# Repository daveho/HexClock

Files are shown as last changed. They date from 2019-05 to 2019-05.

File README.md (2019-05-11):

# HexClock

This is a somewhat silly project to make a digital clock that displays the current time (hour and minute) in hexadecimal.

Here is a picture of the prototype (click to embiggen):

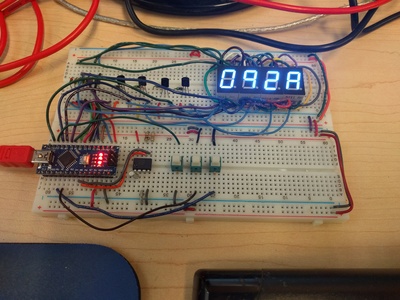
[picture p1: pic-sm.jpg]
HexClock prototype


The [KiCad](http://kicad-pcb.org/) schematic for the prototype circuit is in the [hw\_proto](hw_proto) directory.  The required parts are:

* Arduino Nano
* DS1307 i2c real time clock chip
* 4 common anode 7 segment displays
* 4 2N3906 PNP transistors (to switch common anode voltages for LED displays)
* 4 4.7k Ohm resistors (to drive gates of the PNP transistors)
* 2 1K pull-up resistors for i2c SDA and SCL lines
* 7 current limiting resistors for segment cathodes (I used 220 Ohm)
* 3 normally open pushbutton switches
* 5V power supply of some kind

The software is in the [HexClock](HexClock) directory.  It requires the [RTCLib](https://github.com/adafruit/RTClib) and [Bounce2](https://github.com/thomasfredericks/Bounce2) libraries, both of which you can install using the Arduino package manager.

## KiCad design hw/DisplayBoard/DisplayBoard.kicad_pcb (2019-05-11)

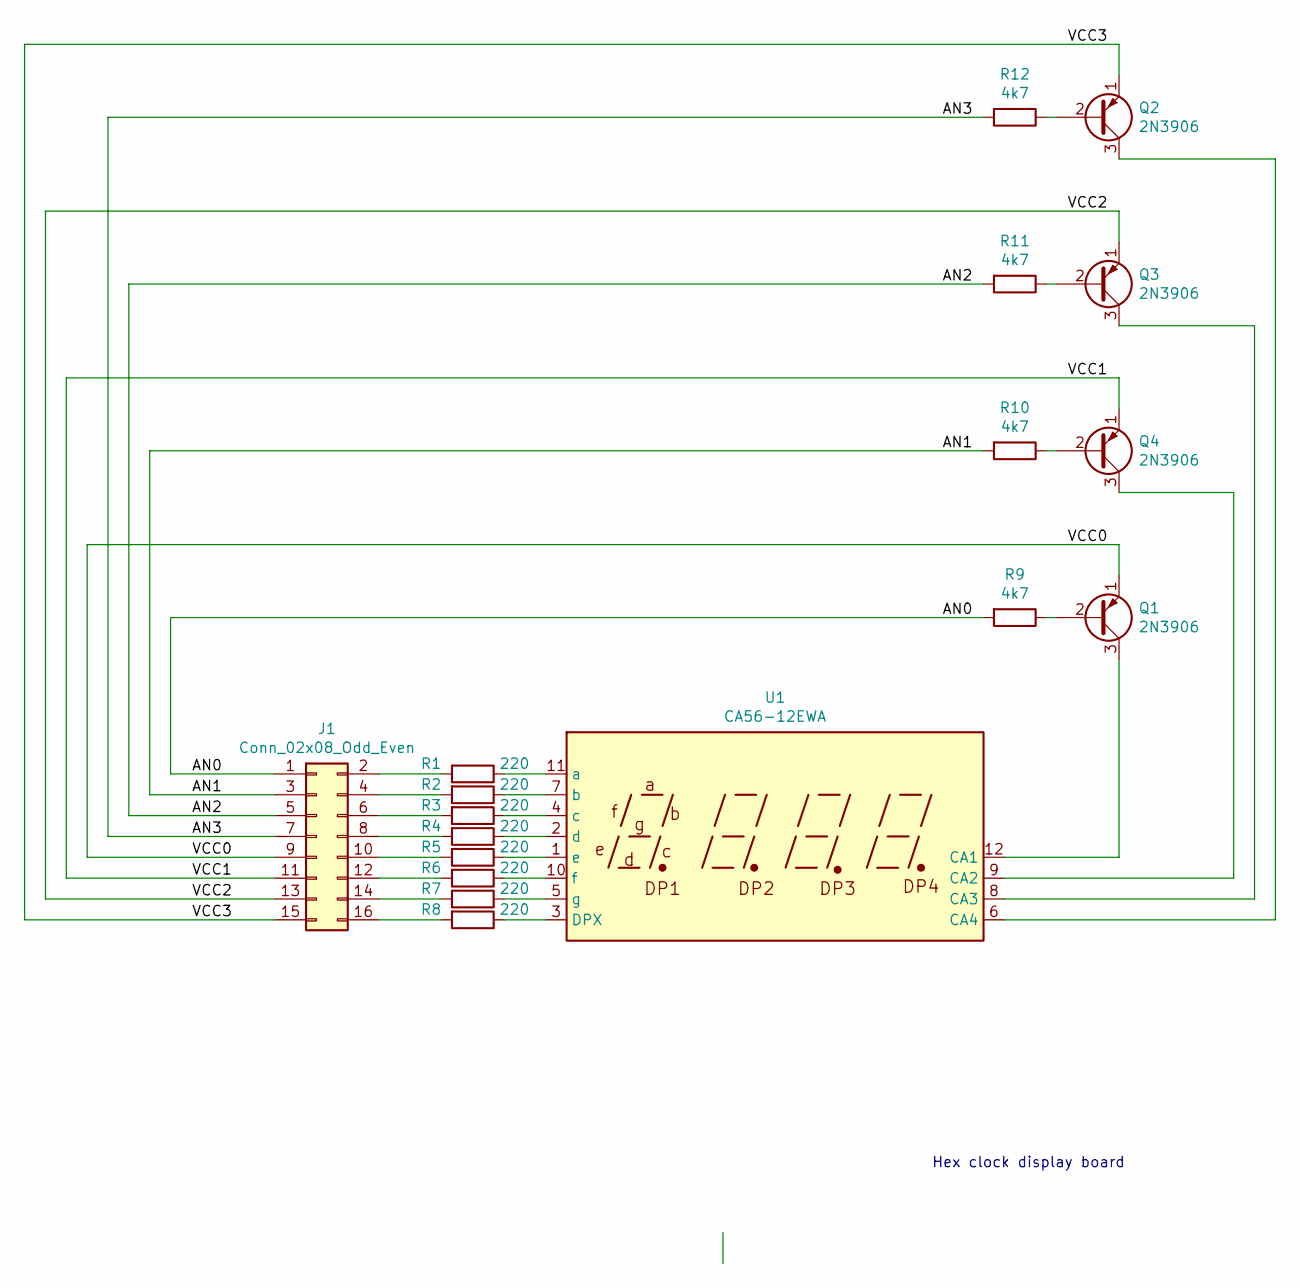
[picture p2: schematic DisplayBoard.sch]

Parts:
J1: Conn_02x08_Odd_Even; Pin_Header_Straight_2x08_Pitch2.54mm
Q1, Q2, Q3, Q4: 2N3906; TO-92_Inline_Narrow_Oval
R1, R2, R3, R4, R5, R6, R7, R8: 220; R_Axial_DIN0207_L6.3mm_D2.5mm_P7.62mm_Horizontal
R9, R10, R11, R12: 4k7; R_Axial_DIN0207_L6.3mm_D2.5mm_P7.62mm_Horizontal
U1: CA56-12EWA

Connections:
/AN0: J1.1, R9.2
/AN1: J1.3, R10.2
/AN2: J1.5, R11.2
/AN3: J1.7, R12.2
/VCC0: J1.9, Q1.1 (E)
/VCC1: J1.11, Q4.1 (E)
/VCC2: J1.13, Q3.1 (E)
/VCC3: J1.15, Q2.1 (E)
unnamed: J1.2, R1.2
unnamed: J1.4, R2.2
unnamed: J1.6, R3.2
unnamed: J1.8, R4.2
unnamed: J1.10, R5.2
unnamed: J1.12, R6.2
unnamed: J1.14, R7.2
unnamed: J1.16, R8.2
unnamed: Q1.2 (B), R9.1
unnamed: Q1.3 (C), U1.12 (CA1)
unnamed: Q2.2 (B), R12.1
unnamed: Q2.3 (C), U1.6 (CA4)
unnamed: Q3.2 (B), R11.1
unnamed: Q3.3 (C), U1.8 (CA3)
unnamed: Q4.2 (B), R10.1
unnamed: Q4.3 (C), U1.9 (CA2)
unnamed: R1.1, U1.11 (a)
unnamed: R2.1, U1.7 (b)
unnamed: R3.1, U1.4 (c)
unnamed: R4.1, U1.2 (d)
unnamed: R5.1, U1.1 (e)
unnamed: R6.1, U1.10 (f)
unnamed: R7.1, U1.5 (g)
unnamed: R8.1, U1.3 (DPX)

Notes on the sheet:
Hex clock display board

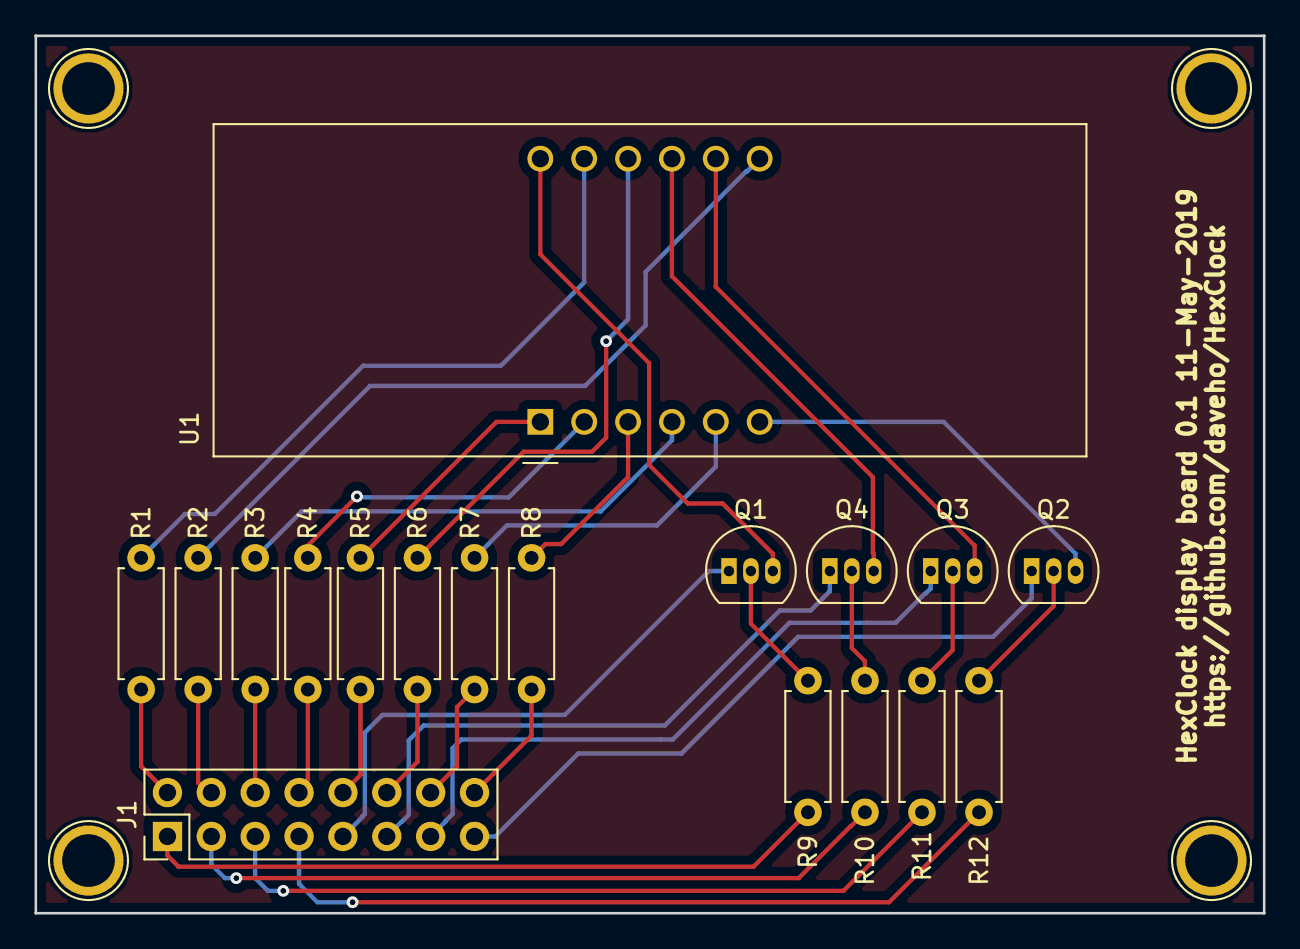
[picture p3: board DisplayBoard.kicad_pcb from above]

Board: 2 copper layers, 71.1 x 50.8 mm, 18 parts (0 on the bottom side), 32 nets.

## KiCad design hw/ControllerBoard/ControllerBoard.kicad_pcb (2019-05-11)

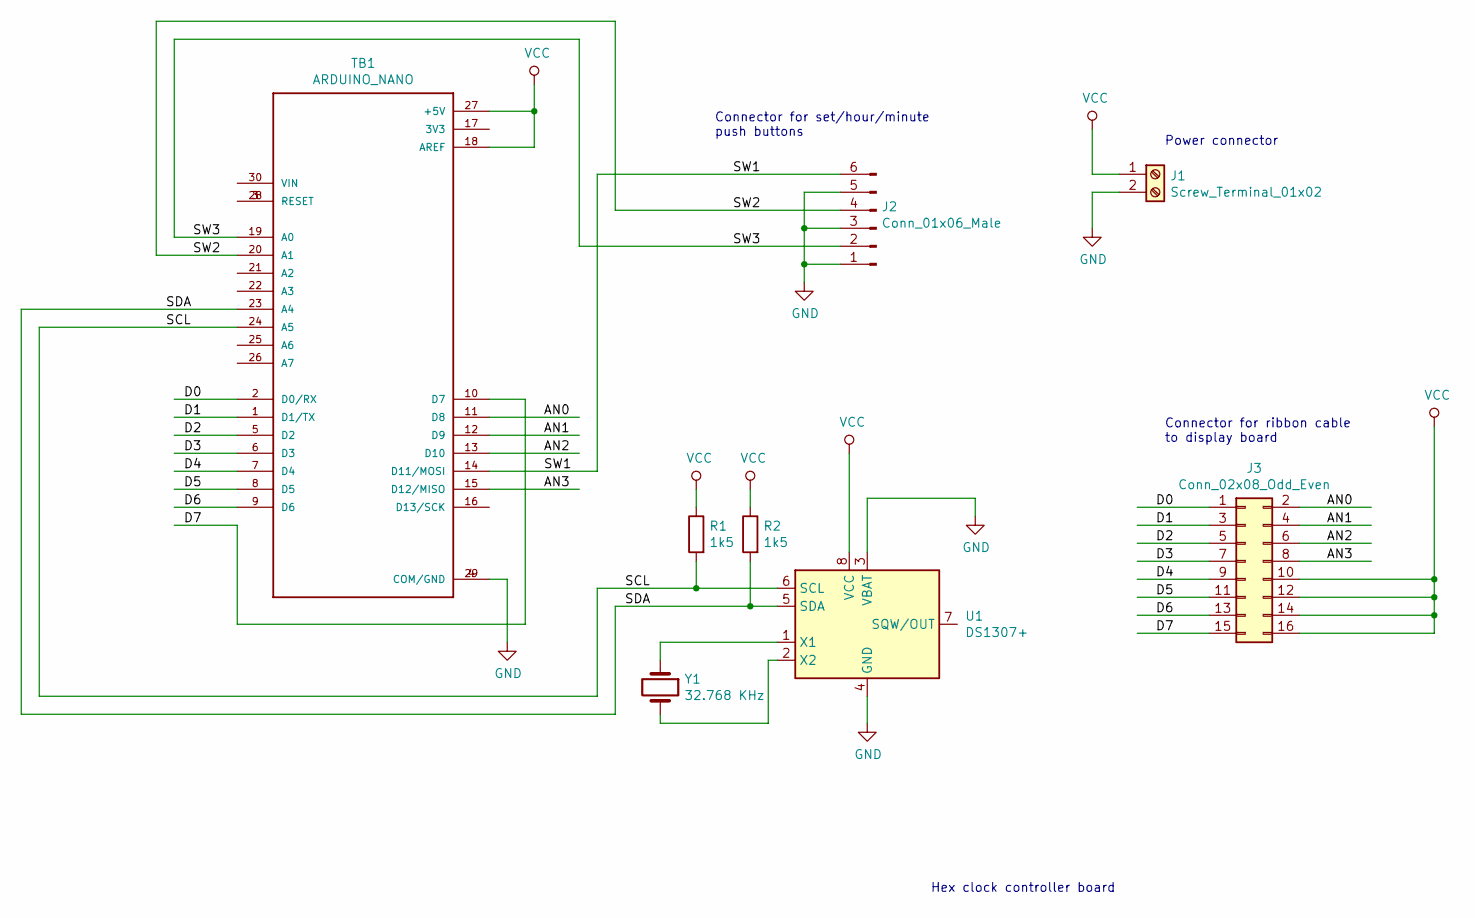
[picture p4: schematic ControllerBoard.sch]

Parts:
J1: Screw_Terminal_01x02; TerminalBlock_Phoenix_MKDS-1,5-2_1x02_P5.00mm_Horizontal
J2: Conn_01x06_Male; Pin_Header_Straight_1x06_Pitch2.54mm
J3: Conn_02x08_Odd_Even; Pin_Header_Straight_2x08_Pitch2.54mm
R1, R2: 1k5; R_Axial_DIN0207_L6.3mm_D2.5mm_P7.62mm_Horizontal
TB1: ARDUINO_NANO; SHIELD_ARDUINO_NANO
U1: DS1307+; DIP-8_W7.62mm_Socket
Y1: 32.768 KHz; Crystal_C38-LF_d3.0mm_l8.0mm_Horizontal

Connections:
/AN0: J3.2, TB1.11 (D8)
/AN1: J3.4, TB1.12 (D9)
/AN2: J3.6, TB1.13 (D10)
/AN3: J3.8, TB1.15 (D12/MISO)
/D0: J3.1, TB1.2 (D0/RX)
/D1: J3.3, TB1.1 (D1/TX)
/D2: J3.5, TB1.5 (D2)
/D3: J3.7, TB1.6 (D3)
/D4: J3.9, TB1.7 (D4)
/D5: J3.11, TB1.8 (D5)
/D6: J3.13, TB1.9 (D6)
/D7: J3.15, TB1.10 (D7)
/SCL: R1.2, TB1.24 (A5), U1.6 (SCL)
/SDA: R2.2, TB1.23 (A4), U1.5 (SDA)
/SW1: J2.6, TB1.14 (D11/MOSI)
/SW2: J2.4, TB1.20 (A1)
/SW3: J2.2, TB1.19 (A0)
GND: J1.2, J2.1, J2.3, J2.5, TB1.4 (COM/GND), TB1.29 (COM/GND), U1.3 (VBAT), U1.4 (GND)
unnamed: TB1.3 (RESET), TB1.28 (RESET)
unnamed: U1.1 (X1), Y1.1
unnamed: U1.2 (X2), Y1.2
VCC: J1.1, J3.10, J3.12, J3.14, J3.16, R1.1, R2.1, TB1.18 (AREF), TB1.27 (+5V), U1.8 (VCC)

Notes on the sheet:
Hex clock controller board
Power connector
Connector for set/hour/minute push buttons
Connector for ribbon cable to display board

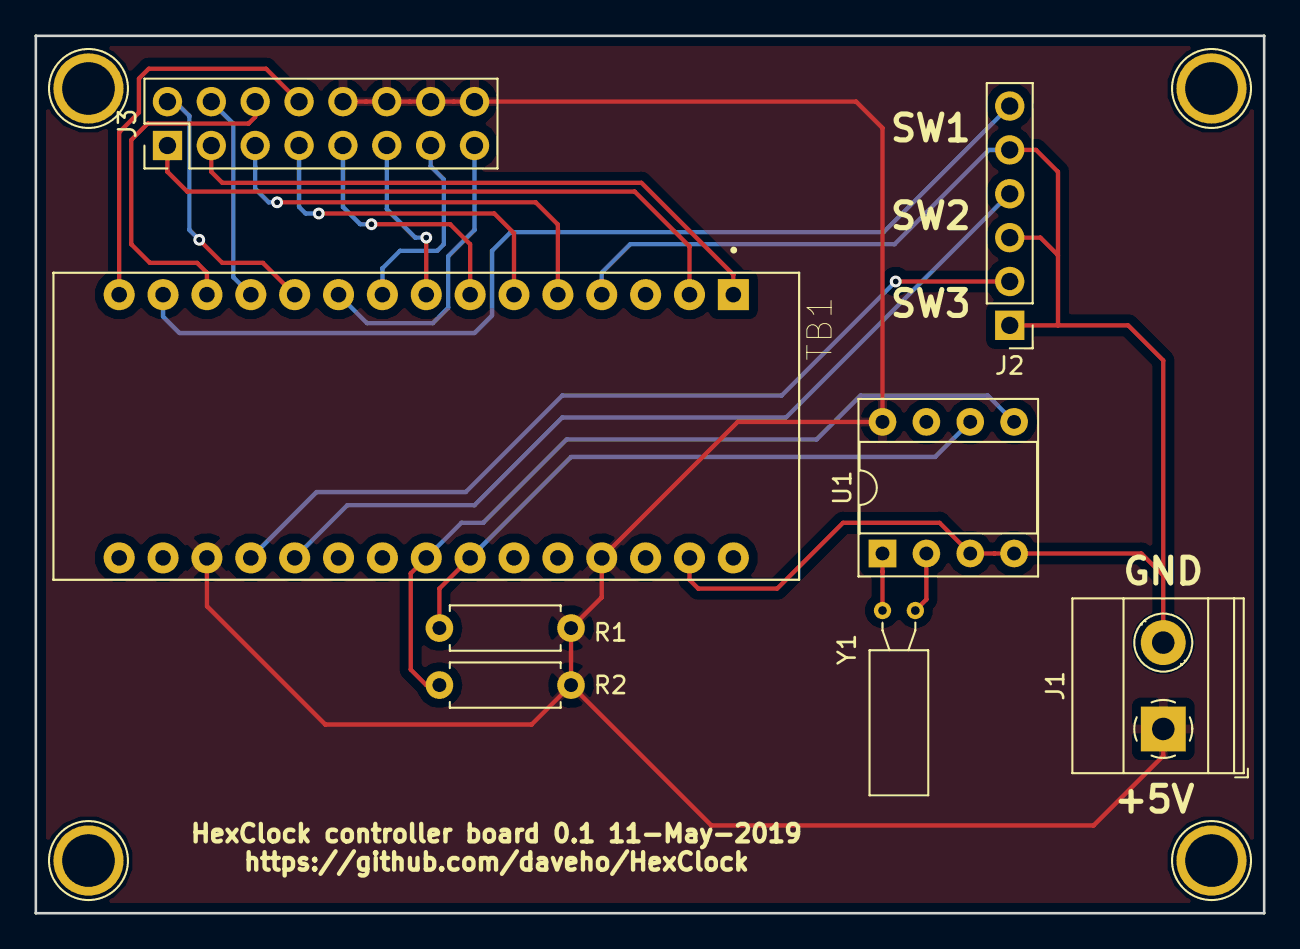
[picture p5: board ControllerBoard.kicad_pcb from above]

Board: 2 copper layers, 71.1 x 50.8 mm, 8 parts (0 on the bottom side), 22 nets.

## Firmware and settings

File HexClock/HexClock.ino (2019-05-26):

#include <stdint.h>
#include <RTClib.h>
#include <Bounce2.h>

//**********************************************************************
// Constant data
//**********************************************************************

// Bits for display segments
#define SEG_A  (1<<0)
#define SEG_B  (1<<1)
#define SEG_C  (1<<2)
#define SEG_D  (1<<3)
#define SEG_E  (1<<4)
#define SEG_F  (1<<5)
#define SEG_G  (1<<6)
#define SEG_DP (1<<7)

// Bit patterns for hex digits 0-9, A-F.
// They are negated because the LED displays are common anode
// and the segments are turned on with a low voltage applied
// to the cathodes.
const uint8_t g_hexfont[16] = {
  (uint8_t) ~(SEG_A|SEG_B|SEG_C|SEG_D|SEG_E|SEG_F),
  (uint8_t) ~(SEG_B|SEG_C),
  (uint8_t) ~(SEG_A|SEG_B|SEG_D|SEG_E|SEG_G),
  (uint8_t) ~(SEG_A|SEG_B|SEG_C|SEG_D|SEG_G),
  (uint8_t) ~(SEG_B|SEG_C|SEG_F|SEG_G),
  (uint8_t) ~(SEG_A|SEG_C|SEG_D|SEG_F|SEG_G),
  (uint8_t) ~(SEG_A|SEG_C|SEG_D|SEG_E|SEG_F|SEG_G),
  (uint8_t) ~(SEG_A|SEG_B|SEG_C),
  (uint8_t) ~(SEG_A|SEG_B|SEG_C|SEG_D|SEG_E|SEG_F|SEG_G),
  (uint8_t) ~(SEG_A|SEG_B|SEG_C|SEG_F|SEG_G),
  (uint8_t) ~(SEG_A|SEG_B|SEG_C|SEG_E|SEG_F|SEG_G),
  (uint8_t) ~(SEG_C|SEG_D|SEG_E|SEG_F|SEG_G),
  (uint8_t) ~(SEG_D|SEG_E|SEG_G),
  (uint8_t) ~(SEG_B|SEG_C|SEG_D|SEG_E|SEG_G),
  (uint8_t) ~(SEG_A|SEG_D|SEG_E|SEG_F|SEG_G),
  (uint8_t) ~(SEG_A|SEG_E|SEG_F|SEG_G),
};

// Port D (digital pins 0..7) drives the segment cathodes
#define DIGIT_OUT  PORTD
#define DIGIT_DDR  DDRD

// Common anode control pins
const uint8_t CA_PINS[] = { 8, 9, 10, 12 };

// Timing delay: should be 1 ms
#define TIMING_DELAY_MS 1

// States for when the set button is pressed
enum {
  // Set is not pressed
  SET_NOT_PRESSED=0,
  // Set is pressed, and hour/minute have not be pressed
  SET_PRESSED,
  // Set is pressed, but hour and/or minute buttons have been
  // pressed to set the time
  SET_HR_MIN_CHANGED,
  // Set was pressed for long enough that a mode change occurred,
  // and now hour/minute changes will be ignored
  SET_MODE_CHANGED,
};

// If set is pressed for this many milliseconds, change the display mode
#define DISPLAY_MODE_CHANGE_MS 3000

//**********************************************************************
// Global variables
//**********************************************************************

// Variables for the time display
volatile uint8_t g_hour;
volatile uint8_t g_minute;

// Used for timing in the main loop
uint16_t count = 0;

// The RTC object (from RTClib)
RTC_DS1307 rtc;

// Debouncing of pushbuttons
Bounce set_btn, hour_btn, minute_btn;

// State of 2nd display decimal point, which blinks
// on/off at about .5 Hz.
uint8_t blinker;

// Display mode: 0=hex, 1=dec
uint8_t display_mode;

// State associated with set button presses
uint8_t set_state;

// Counter that increments while set is pressed
uint16_t set_count;

// Display update count (for multiplexing)
static uint8_t update_count;

//**********************************************************************
// Functions
//**********************************************************************

// Update the LED displays based on current hour and minute
void update_display() {
  // Each time update_display() is called, one LED display
  // is driven with the appropriate digit (and the other
  // displays are turned off.)
  uint8_t which = update_count & 0x3;
  uint8_t val;
  switch (which) {
  case 0: // high digit of hour
    val = (g_hour >> 4) & 0x0F;
    digitalWrite(CA_PINS[3], HIGH);
    digitalWrite(CA_PINS[0], LOW);
    DIGIT_OUT = g_hexfont[val];
    break;
  case 1: // low digit of hour
    val = g_hour & 0x0F;
    digitalWrite(CA_PINS[0], HIGH);
    digitalWrite(CA_PINS[1], LOW);
    DIGIT_OUT = g_hexfont[val] & (blinker ? ~SEG_DP : 0xFF);
    break;
  case 2: // high digit of minute
    val = (g_minute >> 4) & 0x0F;
    digitalWrite(CA_PINS[1], HIGH);
    digitalWrite(CA_PINS[2], LOW);
    DIGIT_OUT = g_hexfont[val];
    break;
  case 3: // low digit of minute
    val = g_minute & 0x0F;
    digitalWrite(CA_PINS[2], HIGH);
    digitalWrite(CA_PINS[3], LOW);
    DIGIT_OUT = g_hexfont[val];
    break;
  }
  update_count++;
}

uint8_t high_digit(uint8_t x) {
  uint8_t count = 0;
  while (x >= 10) {
    count++;
    x -= 10;
  }
  return count;
}

uint8_t low_digit(uint8_t x) {
  while (x >= 10) {
    x -= 10;
  }
  return x;
}

void update_display_dec() {
  uint8_t which = update_count & 0x3;
  uint8_t val;
  switch (which) {
    case 0:
      val = high_digit(g_hour);
      digitalWrite(CA_PINS[3], HIGH);
      digitalWrite(CA_PINS[0], LOW);
      DIGIT_OUT = g_hexfont[val];
      break;
    case 1:
      val = low_digit(g_hour);
      digitalWrite(CA_PINS[0], HIGH);
      digitalWrite(CA_PINS[1], LOW);
      DIGIT_OUT = g_hexfont[val] & (blinker ? ~SEG_DP : 0xFF);
      break;
    case 2:
      val = high_digit(g_minute);
      digitalWrite(CA_PINS[1], HIGH);
      digitalWrite(CA_PINS[2], LOW);
      DIGIT_OUT = g_hexfont[val];
      break;
    case 3:
      val = low_digit(g_minute);
      digitalWrite(CA_PINS[2], HIGH);
      digitalWrite(CA_PINS[3], LOW);
      DIGIT_OUT = g_hexfont[val] & ~SEG_DP; // dp of last digit indicates dec mode
      break;
  }
  update_count++;
}

void update_time(DateTime now) {
  g_hour = now.hour();
  g_minute = now.minute();
}

void check_time() {
  DateTime now = rtc.now();
  if (g_hour != now.hour() || g_minute != now.minute()) {
    update_time(now);
  }
}

void setup() {
  // put your setup code here, to run once:

  // All bits of DIGIT_OUT are configured as outputs
  DIGIT_DDR = 0xFF;

  // Set up common anode control pins
  for (uint8_t i = 0; i < 4; i++) {
    pinMode(CA_PINS[i], OUTPUT);
    digitalWrite(CA_PINS[i], HIGH);
  }

  while (!rtc.begin()) {
    // Couldn't find RTC?
  }

  // Set initial time, otherwise clock doesn't seem
  // to start running
  DateTime set(2019, 5, 15, 0, 0, 0);
  rtc.adjust(set);

  // Set the time according to the RTC
  update_time(rtc.now());

  // Debouncing of pushbuttons
  set_btn.attach(11, INPUT_PULLUP);
  set_btn.interval(10);
  hour_btn.attach(A1, INPUT_PULLUP);
  hour_btn.interval(10);
  minute_btn.attach(A0, INPUT_PULLUP);
  minute_btn.interval(10);
}

void loop() {
  // Update button states
  set_btn.update();
  hour_btn.update();
  minute_btn.update();

  // Blink second display's decimal point at about .5 Hz
  if ((count & 0x3FF) == 0) {
    blinker = !blinker;
  }

  // Check time periodically
  if ((count & 0x3F) == 0) {
    check_time();
  }

  // Refresh display periodically
  if ((count & 0x3) == 0) {
    if (display_mode == 0) {
      update_display();      // hex mode
    } else {
      update_display_dec();  // dec mode
    }
  }

  // Handle set state
  if (set_btn.read()) {
    // Set is not pressed
    set_state = SET_NOT_PRESSED;
    set_count = 0;
  } else {
    switch (set_state) {
      case SET_NOT_PRESSED:
        // Set has just been pressed
        set_state = SET_PRESSED;
        break;
      case SET_PRESSED:
        // Increment set count
        set_count++;
        // If set has been pressed long enough, change display mode
        if (set_count > DISPLAY_MODE_CHANGE_MS) {
          display_mode = !display_mode;
          set_state = SET_MODE_CHANGED;
        }
        break;
    }
  }

  uint8_t change_time_allowed = (set_state == SET_PRESSED || set_state == SET_HR_MIN_CHANGED);

  // Check whether buttons are being used to adjust the time.
  // All buttons are high when not pressed, and low when pressed.
  // The set button must be pressed for the hour and minute
  // adjust buttons to be used.
  bool adjust = false;
  if (hour_btn.fell() && change_time_allowed) {
    // Adjust hour
    g_hour++;
    if (g_hour >= 24) { g_hour = 0; }
    adjust = true;
  }
  if (minute_btn.fell() && change_time_allowed) {
    // Adjust minute
    g_minute++;
    if (g_minute >= 60) { g_minute = 0; }
    adjust = true;
  }
  if (adjust) {
    // Time was changed, so update RTC
    DateTime cur = rtc.now();
    DateTime adj(cur.year(), cur.month(), cur.day(), g_hour, g_minute, 0);
    rtc.adjust(adj);

    // Set state to SET_HR_MIN_CHANGED (if it was not already):
    // this ensures that we won't trigger an unintended mode change
    set_state = SET_HR_MIN_CHANGED;
  }

  // Timing delay
  delay(TIMING_DELAY_MS);
  
  count++;
}

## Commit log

2019-04-26 initial schematic for hardware
    [HexClock.kicad_pcb, HexClock.sch]
2019-04-26 annotated schematic
    [HexClock.sch]
2019-04-27 use Arduino Nano symbol that has correct pinout
    arduino_nano.lib has the TX and RX pins swapped
    [HexClock.sch]
2019-04-30 changed not to use interrupts
2019-04-30 After bugfixes, seems to be working
    Removed the for loop from the loop() function. (Duh.)
    Button 2 is now connected to A1 rather than D13: the
    LED and resistor connected to D13 makes it unsuitable
    as a digital input.
    Still need to clean up the code.
    [HexClock.sch]
2019-05-01 corrected a code comment
    [HexClock.ino]
2019-05-01 minor correction to code comment
    [HexClock.ino]
2019-05-03 added picture of prototype
2019-05-05 set time to midnight on startup
    If the time is not set then the clock doesn't
    seem to run.
    Also, make timing delay a named constant (slowing
    it down is helpful for debugging.)
    [HexClock.ino]
2019-05-05 power via 5V pin
    Powering via VIN produces strange behavior...
    not sure why.
    [HexClock.sch]
2019-05-11 tie DS1307 VBAT to ground
    I could not get the DS1307 to work correctly with
    the battery connected.
    [HexClock.sch]
2019-05-11 moved KiCad project to "hw_proto" directory
    The "production" version of the hardware will
    be two projects, one for the display PCB, one
    for the controller PCB.
    [HexClock.kicad_pcb, HexClock.sch]
2019-05-11 start display board project
    [DisplayBoard.kicad_pcb, DisplayBoard.sch]
2019-05-11 edited to make this just the display board
    Also, changed to use a 4 digit LED display.
    [DisplayBoard.sch]
2019-05-11 generated netlist
    [DisplayBoard.sch]
2019-05-11 choose component footprints
    [DisplayBoard.sch]
2019-05-11 reexport netlist with component footprints
2019-05-11 working on PCB layout
    [DisplayBoard.kicad_pcb, DisplayBoard.sch]
2019-05-11 routed all traces
    [DisplayBoard.kicad_pcb]
2019-05-11 copper pours on both copper layers
    [DisplayBoard.kicad_pcb]
2019-05-11 started controller board project
    [ControllerBoard.kicad_pcb, ControllerBoard.sch]
2019-05-11 updated schematic for controller board
    [ControllerBoard.sch]
2019-05-11 annotated with component footprints
    [ControllerBoard.sch]
2019-05-11 fix some footprints, start PCB
    [ControllerBoard.kicad_pcb, ControllerBoard.sch]
2019-05-11 routed all nets, board is ready?
    [ControllerBoard.kicad_pcb]
2019-05-11 generated gerber files
    [ControllerBoard-B.Cu.gbl, ControllerBoard-B.Mask.gbs, ControllerBoard-B.SilkS.gbo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]
2019-05-11 ignore gerber zipfile
2019-05-11 generated (correct?) gerber files
    [ControllerBoard.kicad_pcb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]
2019-05-26 long press of set button changes display mode
    The decimal display mode isn't actually implemented
    yet.
